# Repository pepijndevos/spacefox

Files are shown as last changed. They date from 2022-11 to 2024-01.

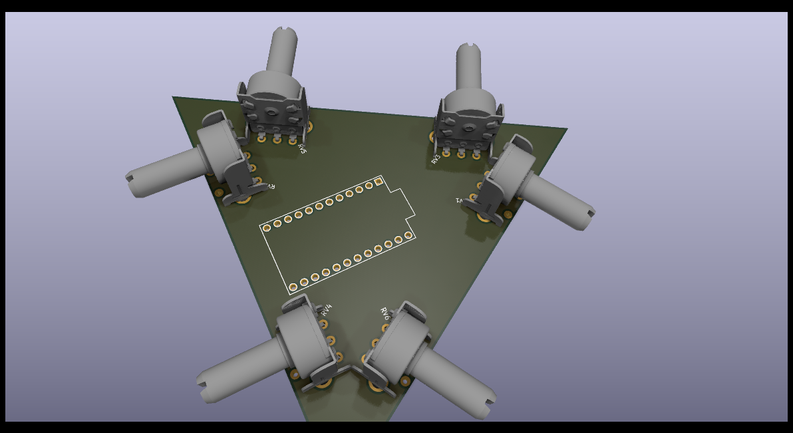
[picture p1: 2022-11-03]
spacefox/spacefox.png

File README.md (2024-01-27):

# SpaceFox

A 6DOF DIY HID. A what? A 6 degrees of freedom, do it yourself, human interface device. In other words, a 3D mouse, or an open hardware SpaceNavigator. You know, one of these thingies CAD designers use to zoom around.

All the existing DIY designs out there I could find are not actually 6DOF. Some are literally a knob on a joystick. So I set out to make a better one.

This one is based on a stewart platform made from potentiometers. It was designed so that any idiot with access to a 3D printer can build one. You might even get away with some careful jigsawing!

## Other true 6DOF projects

Since doing this project I've become aware of a few other people making true 6DOF DIY spacemice that may actually be worth your time.

* [Space Mushroom](https://www.instructables.com/Space-Mushroom-Full-6-DOFs-Controller-for-CAD-Appl/)
* [Haptick](https://blog.ioces.com/matt/posts/haptick-part-two/)

## Gallery

Watch the Youtube video:

Watch the video (https://youtu.be/axdTv2XX5zU)

Close-up of the spring-loaded potentiometers:



CAD model of one of the arms:



CAD model of the knob:



CAD model of the base



## Bill of Materials

* 3x arm-Body + arm2-Body, 3D printed.
* 1x top-Body, 3D printed.
* 1x base, cut from 4 layers of 4mm triplex.
* 1x PCB [Aisler](https://aisler.net/p/TOQVENVP)
* 6x potentiometer, 6mm flatted shaft [Farnell](https://nl.farnell.com/tt-electronics-bi-technologies/p120k-f20br5k/potentiometer-rotary-5k-20mm-20/dp/2771751)
* 1x Arduino Pro Micro [Sparkfun](https://www.sparkfun.com/products/12640) [AliExpress](https://www.aliexpress.com/item/32768308647.html)
* 12x ball joint rod ends, 2mm, half pad [AliExpress](https://www.aliexpress.com/item/1005003423670988.html)
* 6x torsion spring, 1mm diameter, 3mm length, 90 degrees, 8.5mm outer diameter [AliExpress](https://www.aliexpress.com/item/1005003823259348.html)
* 6x threaded rod, 2mm, 20mm length [AliExpress](https://nl.aliexpress.com/item/1005002781646885.html)
* 9x Cherry MX compatible switches [AliExpress](https://nl.aliexpress.com/item/1005004285423123.html)
* 9x keycaps [AliExpress](https://nl.aliexpress.com/item/1005003302173904.html)
* 2mm & 3mm nuts and bolts
* 0.1" male & female headers

## Assembly instructions

1. Put the springs on the potentionmeters and snap them onto the PCB. Solder. Cut the ends short below the PCB.
2. Push the male and female headers together and insert them between the Arduino and PCB. Solder. (This way you ensure they end up straight)
3. Slide the arms halfway onto the potentionmeters facing 45 degree outwards. Apply a drop of hot glue to the slot for the spring and push them all the way in. Apply hot glue to secure the arm to the shaft.
4. Screw the rod ends onto the push rods and secure the rod ends to the arm with nuts and bolts.
5. Secure the knob to the rod ends with bolts.
7. Cut 4 sheets of the base plate (the middle sheet twice)
8. Insert Cherry MX switches in the top plate
9. Wire switches to the header on the PCB
11. Bolt the base plates together
10. Bolt the PCB onto the base plate
6. Upload the Arduino code.
8. Install [spacenavd](https://github.com/FreeSpacenav/spacenavd) and add `device-id = 1b4f:9206` to `/etc/spnavrc`.

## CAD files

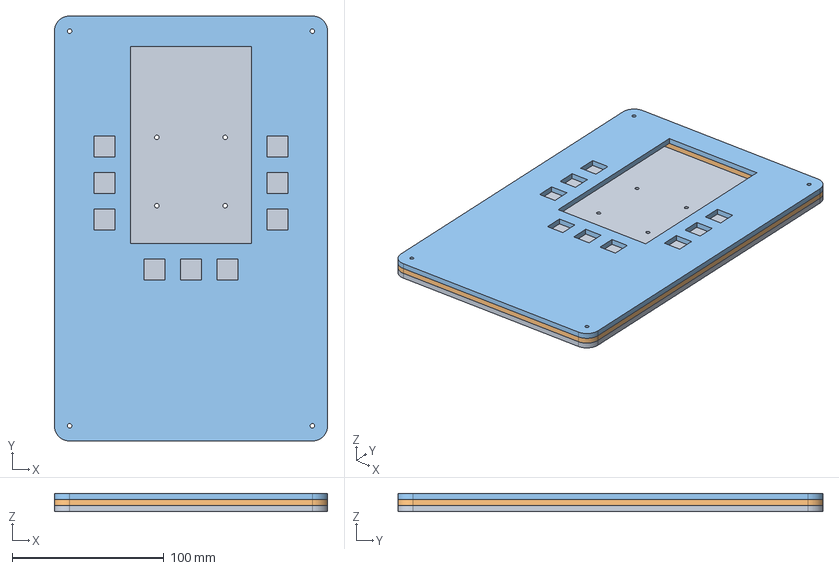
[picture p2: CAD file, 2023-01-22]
base.FCStd
180.0 x 280.0 x 12.0 mm
bottom
middle
top

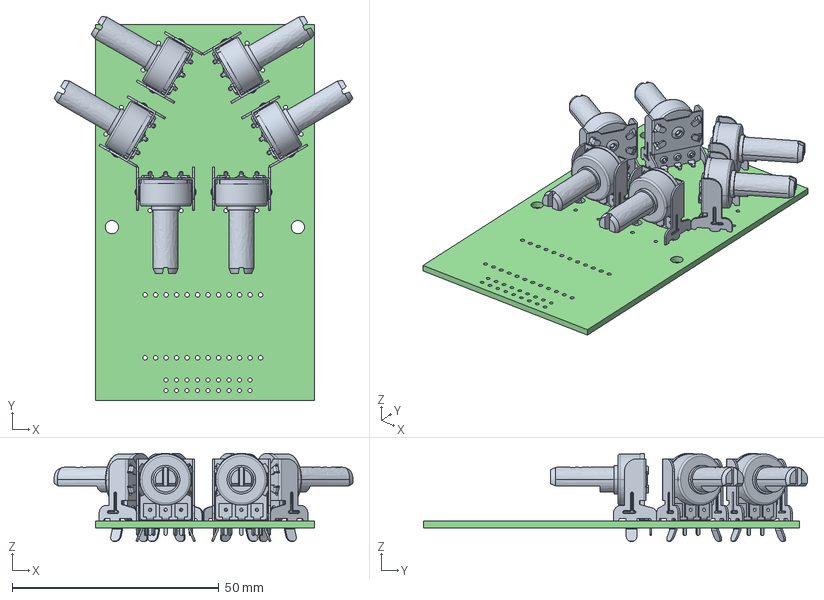
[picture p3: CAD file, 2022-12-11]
spacefox/spacefox.step
72.4 x 93.0 x 21.4 mm
spacefox PCB

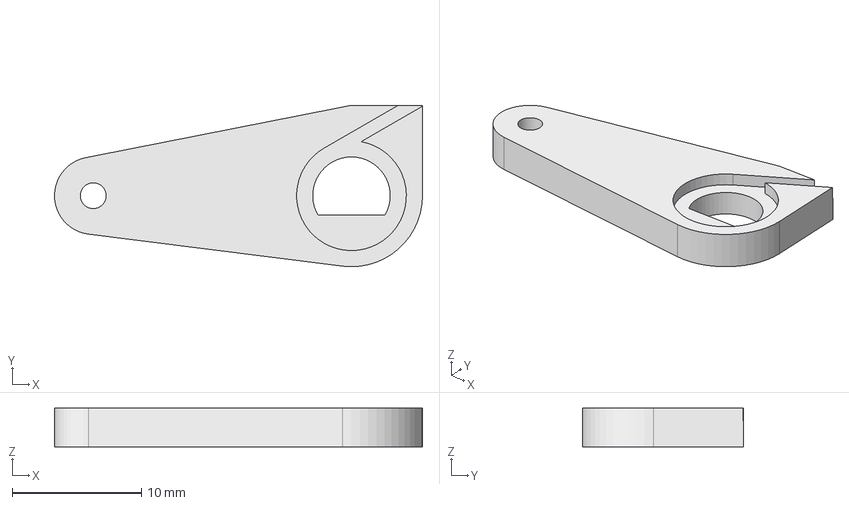
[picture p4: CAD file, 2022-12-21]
arm2.FCStd
28.5 x 12.5 x 3.00 mm

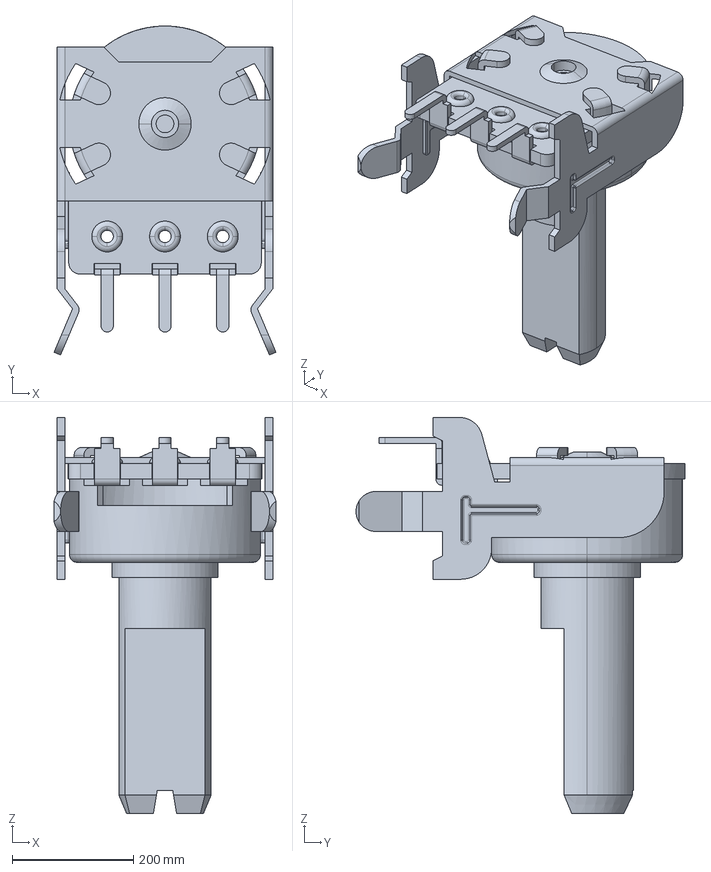
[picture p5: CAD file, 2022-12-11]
spacefox/P120K-F20BR10K.stp
365.8 x 542.3 x 652.8 mm

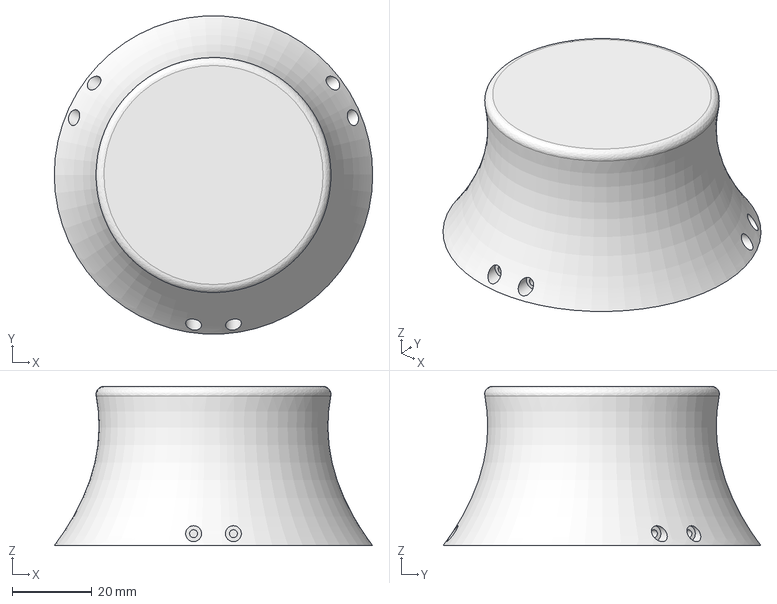
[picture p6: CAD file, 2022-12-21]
top.FCStd
80.0 x 79.9 x 40.0 mm

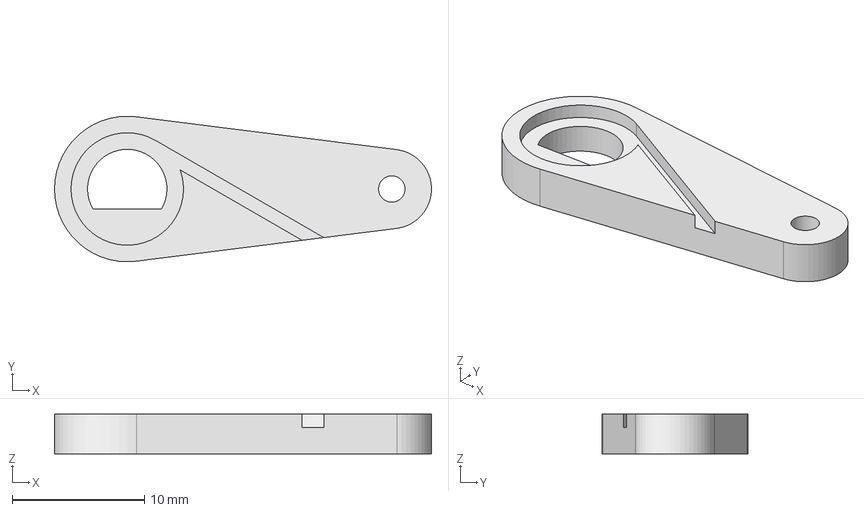
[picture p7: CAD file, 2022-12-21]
arm.FCStd
28.5 x 11.0 x 3.00 mm

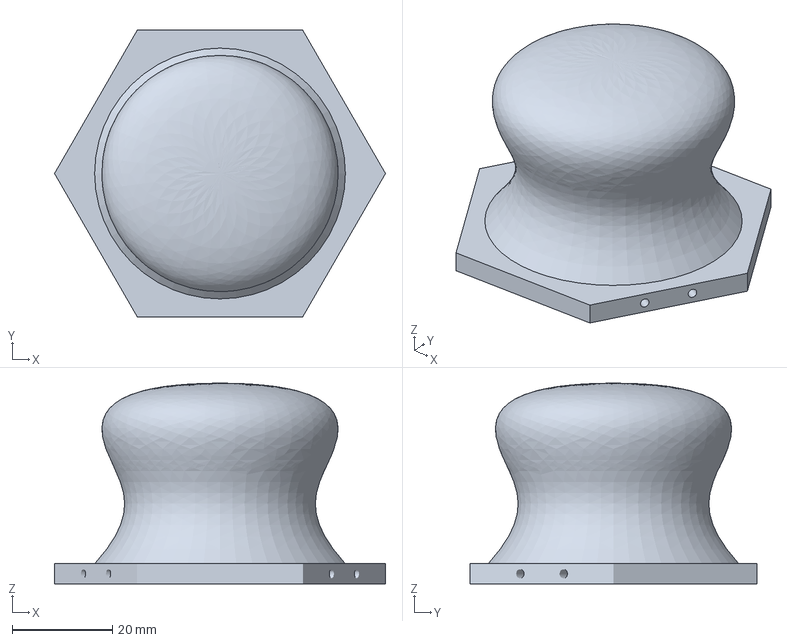
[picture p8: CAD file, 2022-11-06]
top-Body.3mf
66.0 x 57.2 x 40.0 mm

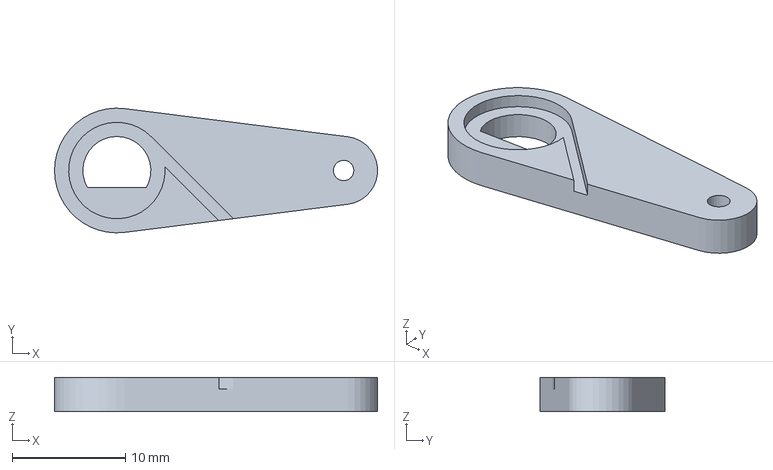
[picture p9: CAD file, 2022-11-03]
arm-Body.3mf
28.5 x 11.0 x 3.00 mm

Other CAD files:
arm2-Body.3mf

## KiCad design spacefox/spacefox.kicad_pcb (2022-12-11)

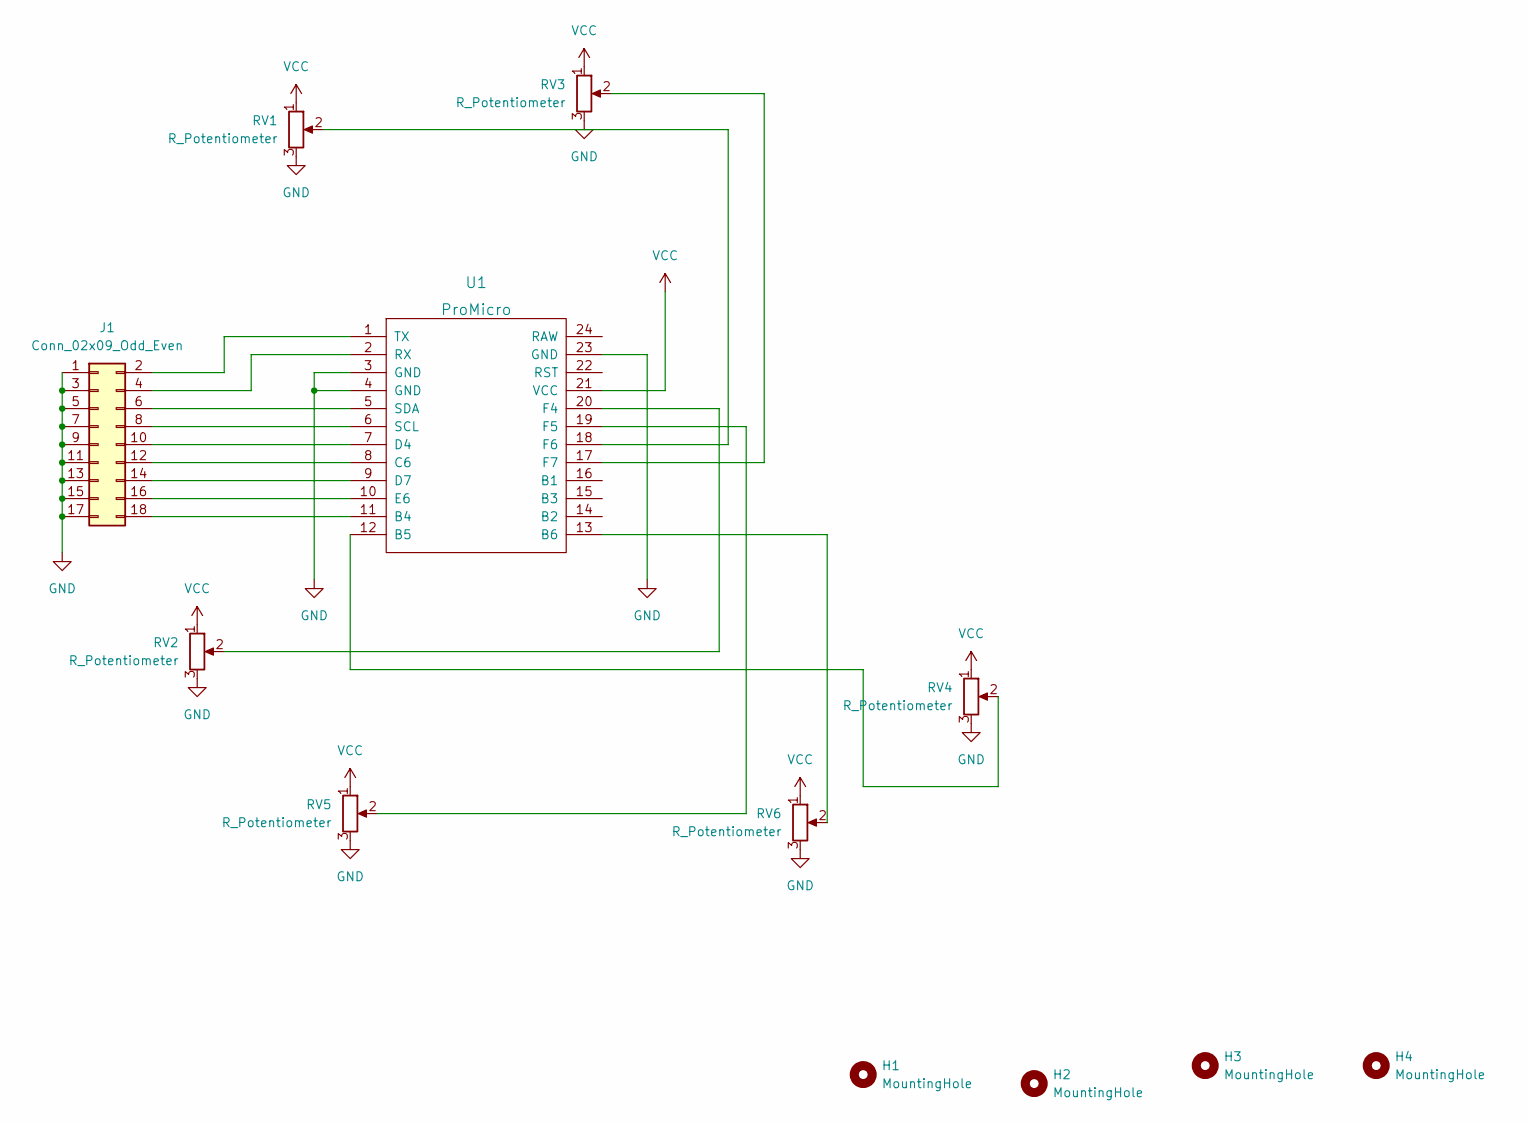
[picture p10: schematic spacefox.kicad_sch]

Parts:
H1, H2, H3, H4: MountingHole; MountingHole_3.2mm_M3
J1: Conn_02x09_Odd_Even; PinHeader_2x09_P2.54mm_Vertical
RV1, RV2, RV3, RV4, RV5, RV6: R_Potentiometer; TT_P120
U1: ProMicro

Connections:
GND: J1.1, J1.3, J1.5, J1.7, J1.9, J1.11, J1.13, J1.15, J1.17, RV1.3, RV2.3, RV3.3, RV4.3, RV5.3, RV6.3, U1.3 (GND), U1.4 (GND), U1.23 (GND)
unnamed: RV1.2, U1.18 (F6)
unnamed: RV2.2, U1.20 (F4)
unnamed: RV3.2, U1.17 (F7)
unnamed: RV4.2, U1.12 (B5)
unnamed: RV5.2, U1.19 (F5)
unnamed: RV6.2, U1.13 (B6)
unnamed: J1.2, U1.1 (TX)
unnamed: J1.4, U1.2 (RX)
unnamed: J1.6, U1.5 (SDA)
unnamed: J1.8, U1.6 (SCL)
unnamed: J1.10, U1.7 (D4)
unnamed: J1.12, U1.8 (C6)
unnamed: J1.14, U1.9 (D7)
unnamed: J1.16, U1.10 (E6)
unnamed: J1.18, U1.11 (B4)
VCC: RV1.1, RV2.1, RV3.1, RV4.1, RV5.1, RV6.1, U1.21 (VCC)

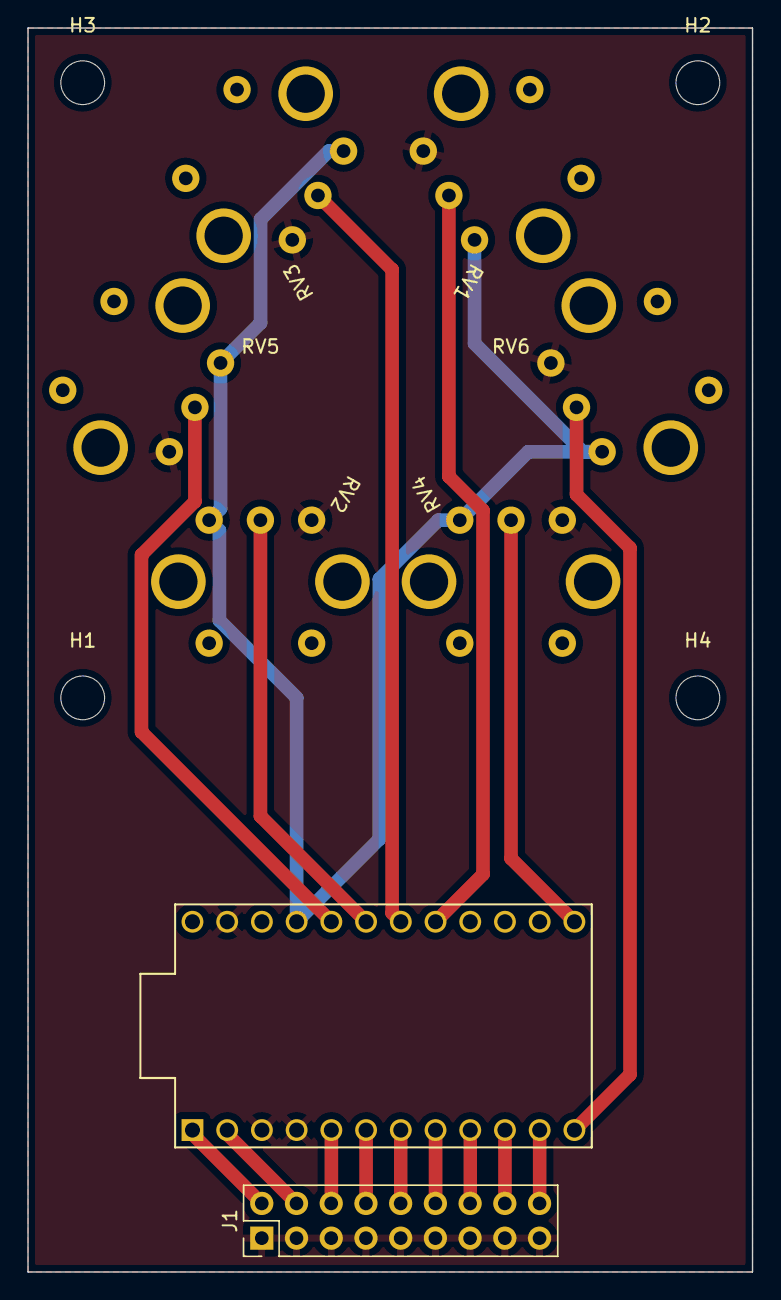
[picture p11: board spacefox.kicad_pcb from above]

Board: 2 copper layers, 53.0 x 91.0 mm, 12 parts (0 on the bottom side), 17 nets.

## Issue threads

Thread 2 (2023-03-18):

''This project has no readme yet.''

kolavq, 2023-03-18:
if the pcb was saved in the link, it does not show the ready project to be ordered.

''This project has no readme yet.''

pepijndevos, 2023-03-18:
I'm sorry I don't understand what you mean

kolavq, 2023-03-18:
I apologize for the problem I'm using a translator. When I click on the link from pcb in Bill of Materials, no ready-made board for the project pops up.
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

pepijndevos, 2023-04-02:
Yes I think you have to make an account with Aisler, and click import.

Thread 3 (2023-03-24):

Where is "Joystick.h"

vgegok, 2023-03-24:
I try This lib, But it doesn't work：
[arduino-JOYSTICK](https://github.com/gmarty2000-ARDUINO/arduino-JOYSTICK)

vgegok, 2023-03-24:
https://github.com/MHeironimus/ArduinoJoystickLibrary
Is't this?

pepijndevos, 2023-03-25:
Yes the latter one looks like the correct one. I'm away from home at the moment, but if that works for you, I'd wlecome a PR to update the readme to mention this.

vgegok, 2023-03-25:
Yes. I tested the latter one,It’s working!
Thanks for your reply! I will close this issue!

Closed 2023-03-25.

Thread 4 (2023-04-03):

Load cell instead of potentiometers?

bob-u, 2023-04-03:
What do you think about using strain sensors instead of potentiometers? I think in such case stewart platform may work similar to IBM eraser mouse (aka trackpoint) only with 6 DOF.

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

pepijndevos, 2023-04-03:
Interesting concept! I toyed with several ideas, and the trouble with most of them was either price or construction.
Where would you obtain suitable strain gauges and how would you construct the device?

bob-u, 2023-04-03:
I think base and top, with necessary cutouts, could be made by PCBway or JLCPSB.  To measure force, stick-on strain gauges, two per leg, in Half-bridge configuration II (based on https://www.transducertechniques.com/wheatstone-bridge.aspx) connected to 3 HX711  (2ch each, 80sps max) amplifiers.  Both can be purchased from Ali or Amazon although I do not know how well they would work in this configuration.  Aluminum standoffs from Aliexpress (https://www.aliexpress.us/item/3256803251548057.html) can be used for legs.

pepijndevos, 2023-04-04:
Yes the potential of being able to make such a device out of a single 3D print and some Sparkfun load cell amplifiers would make it very accessible. Indeed a challenge is not to make it more expensive than an actual 3dconexxion device.

bob-u, 2023-04-05:
I agree.  I like the simplicity and low cost of potentiometers.

Closed 2023-04-05.

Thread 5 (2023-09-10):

no windows support?

ekaggrat, 2023-09-10:
is this device not supported under windows?

pepijndevos, 2023-09-10:
It works as a joystick under windows just fine, but spacenavd doesn't support windows. This means it works great for games but doesn't work with most CAD software.

Note that it'd be possible to emulate a Space Navigator in firmware so it'd work with the official driver on windows, but I didn't do this.

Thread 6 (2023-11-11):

Using spacefox in ROS

suitendaal, 2023-11-11:
Hi,
I came across this spacemouse project where, unlike other DIY spacemouse projects where they just move your mouse with an Arduino, you can actually register the device as spacemouse. Now I want to use this spacemouse in ROS using the [spacenav_node](http://wiki.ros.org/spacenav_node).
I have uploaded a simplified version of your code to an Arduino Micro, where I just send constant values over the joystick. I registered the device to `/etc/spnavrc` and launched the `spacenav_node` in ROS, but I don't get any spacemouse values there. I have a couple of questions:

- Where does the `device-id` of `1b4f:9206` come from?
- How do I verify that the Arduino Micro is actually running as spacemouse device in [spacenavd](https://github.com/FreeSpacenav/spacenavd)?
- Do you know how to get these values in the ROS `spacenav_node`?

Kind regards,
Sven

pepijndevos, 2023-11-11:
The device ID comes form the Arduino and can be seen in  `lsusb`.

I'm not familiar with ROS spacenav, but you can run `spnavcfg` to see if the `spacenavd` daemon is running and the device is registered.

suitendaal, 2023-11-11:
Thank you for your help and reponse! I have now installed `spacenavd`, `libspnav` and `spnavcfg` and I can indeed see that the device is registered.
Am I supposed to see the joystick's values in `spnavcfg`? Because `TX`, `TY`, `TZ`, `RX`, `RY` and `RZ` are all 0. Also, I don't see my button values at the _Buttons_ tab. A snipped of the code on the Arduino looks like this:

```
void loop() {
  // Simulate buttons
  joystick.setButton(0, true);
  joystick.setButton(1, false);
  joystick.setButton(2, true);
  joystick.setButton(3, false);

  // Simulate axes
  joystick.setXAxis(200);
  joystick.setYAxis(300);
  joystick.setZAxis(-400);
  joystick.setRxAxis(0);
  joystick.setRyAxis(10);
  joystick.setRzAxis(-20);

  // Send state
  joystick.sendState();
}
```

pepijndevos, 2023-11-11:
Yes. Does spacenavd have access to the USB device? The brute force method would be running it as root.

suitendaal, 2023-11-13:
Hi, I think I found the issue. Spacenav only reacts to events. With my hardcoded constant values there were no events. Now my loop looks like this:

```
void loop() {
  int x = 512.0 * sin(millis() / 1000.0);
  digitalWrite(LED_BUILTIN, x > 0.0);

  joystick.setButton(0, x > 400);
  joystick.setButton(1, x <= 400);
  joystick.setButton(2, x > 0);
  joystick.setButton(3, x <= 0);

  joystick.setXAxis(x);
  joystick.setYAxis(400);
  joystick.setZAxis(-300);
  joystick.setRxAxis(0);
  joystick.setRyAxis(10);
  joystick.setRzAxis(-20);
  joystick.sendState();
}
```

And indeed I see the `TX` and the buttons change, but not `TY`, `TZ`, `RX`, `RY` and `RZ`, because they remain constant in the Arduino code.

suitendaal, 2023-11-13:
What helped me was running `evtest /dev/input/event4` (with eventX the HID channel on which the Arduino is sending the data, in my case 4). There you can read the current values (which are my constant hardcoded values) and if `spacenavd` is not running, you also receive all the events here.

Closed 2023-11-13.

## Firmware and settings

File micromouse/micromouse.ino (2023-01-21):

#include <Joystick.h>


int i1;
int i2;
int i3;
int i4;
int i5;
int i6;

Joystick_ Joystick;

void setup() {
  Serial.begin(9600);
  Joystick.begin(false);
  Joystick.setXAxisRange(-512, 512);
  Joystick.setYAxisRange(-512, 512);
  Joystick.setZAxisRange(-512, 512);
  Joystick.setRxAxisRange(-512, 512);
  Joystick.setRyAxisRange(-512, 512);
  Joystick.setRzAxisRange(-512, 512);

  pinMode(0, INPUT_PULLUP);
  pinMode(1, INPUT_PULLUP);
  pinMode(2, INPUT_PULLUP);
  pinMode(3, INPUT_PULLUP);
  pinMode(4, INPUT_PULLUP);
  pinMode(5, INPUT_PULLUP);
  pinMode(6, INPUT_PULLUP);
  pinMode(7, INPUT_PULLUP);
  pinMode(8, INPUT_PULLUP);

  i1 = analogRead(A0);
  i2 = analogRead(A9);
  i3 = analogRead(A10);
  i4 = analogRead(A2);
  i5 = analogRead(A3);
  i6 = analogRead(A1);
}

void loop() {
  int s1 = analogRead(A0)-i1;
  int s2 = analogRead(A9)-i2;
  int s3 = analogRead(A10)-i3;
  int s4 = analogRead(A2)-i4;
  int s5 = analogRead(A3)-i5;
  int s6 = analogRead(A1)-i6;

  int cm1 = s1-s2;
  int dm1 = s1+s2;
  int cm2 = s3-s4;
  int dm2 = s3+s4;
  int cm3 = s5-s6;
  int dm3 = s5+s6;

  int y = cm1+cm2+cm3;
  int z = dm1-dm3;
  int x = dm2-dm1/2-dm3/2;
  int ry = dm1+dm2+dm3;
  int rx = cm1/2-cm2+cm3/2;
  int rz = cm1-cm3;

  Joystick.setButton(0, !digitalRead(0));
  Joystick.setButton(1, !digitalRead(1));
  Joystick.setButton(2, !digitalRead(2));
  Joystick.setButton(3, !digitalRead(3));
  Joystick.setButton(4, !digitalRead(4));
  Joystick.setButton(5, !digitalRead(5));
  Joystick.setButton(6, !digitalRead(6));
  Joystick.setButton(7, !digitalRead(7));
  Joystick.setButton(8, !digitalRead(8));
  
  Joystick.setYAxis(y);
  Joystick.setZAxis(z);
  Joystick.setXAxis(x);
  Joystick.setRyAxis(-ry);
  Joystick.setRxAxis(-rx);
  Joystick.setRzAxis(rz);
  
  Joystick.sendState();
}

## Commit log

2022-11-03 update arm for springs
    [arm-Body.3mf, arm.FCStd, arm2-Body.3mf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]
2022-11-03 updated arms
    [arm-Body.3mf, arm.FCStd, arm2-Body.3mf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]
2022-11-05 add arduino code and knob
    [top.FCStd]
2022-11-06 add exported body
    [top-Body.3mf]
2022-11-06 flip axis to match spacenavd
    [micromouse.ino]
2022-11-10 WIP V2 PCB
    [spacefox.kicad_pcb, spacefox.kicad_sch]
2022-12-11 update top knob
    [P120K-F20BR10K.stp, spacefox.kicad_pcb, spacefox.kicad_sch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]
2022-12-21 tweak dimensions
    [arm.FCStd, arm2.FCStd, top.FCStd]
2023-01-17 add base plate
    [base.FCStd]
2023-01-21 update arduino code for v2 PCB
2023-01-22 update base
    [base.FCStd]
